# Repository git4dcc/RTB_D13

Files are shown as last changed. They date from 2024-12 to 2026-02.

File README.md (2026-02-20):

# RTB_D13




My Homebrew [D13](https://rtb4dcc.de/hardware/decoder/d13/) LED decoder is a drop in design for Minitrix (#15791) coach with no mechanical modification required. The decoder is designed to integrate into the [RTB](https://rtb4dcc.de/concept/) digital control infrastructure.

<details>
<summary>See also</summary>

- [RTB_D12 - custom](/../../../../git4dcc/RTB_D12) (Fleischmann V100)
- [RTB_D15 - custom](/../../../../git4dcc/RTB_D15) (Minitrix V160)
- [RTB_D16 - NEM651](/../../../../git4dcc/RTB_D16)
- [RTB_D20 - NEM651](/../../../../git4dcc/RTB_D20)
- [RTB_D21 - Next18](/../../../../git4dcc/RTB_D21)
- [RTB_D22 - Plux16](/../../../../git4dcc/RTB_D22)
- [RTB_D23 - NEM652](/../../../../git4dcc/RTB_D23)

</details>

<details>
<summary>User Guides</summary>

- User Guide - DE
- [User Guide - EN](https://rtb4dcc.de/rtb_decoder_reference_en/)

</details>

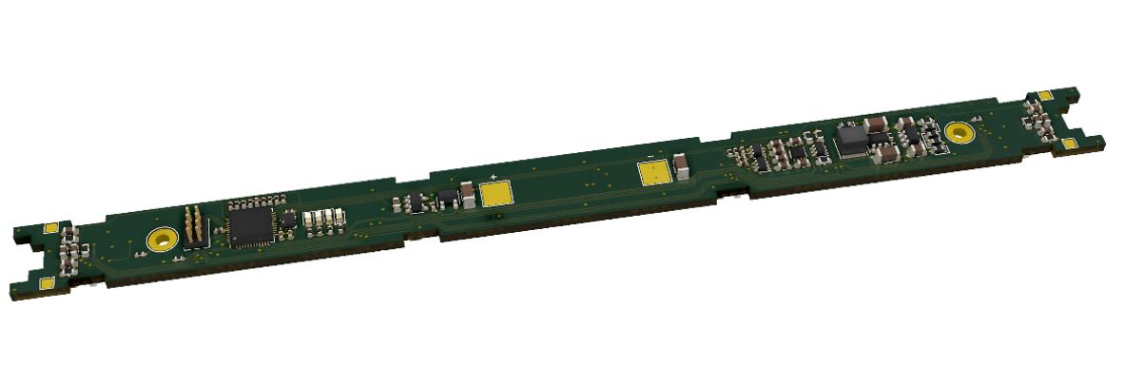
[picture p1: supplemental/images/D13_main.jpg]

<br>

## Decoder features
- **DCC**
  - DCC-A automatic logon
  - DCC-R protocol extension
  - Service Mode Programming
- **Railcom**
  - Channel 1/2
  - POM, xPOM
  - DYN: QoS, Track-Voltage, Scap-Voltage, Temp, Ambient light
- 1x4F/2.8V SCAP (on PCB)
- Inrush limited
- step up/down converter
- max track voltage 25V
- Corridor (11 LEDs), Cabin (13 LEDs), Lavatory (2 LEDs)
- Status LEDs: heartbeat, charging, no-power
- motion sensor
- ambient light sensor
- fast firmware update within seconds on main tracks via DCC-R

# Hardware
The current PCB layout uses SMD footprints with 0.5mm pitch and mainly 0603 parts. Reflow soldering is recommended whereas handsoldering will be difficult.

## PCB
- 4-layer PCB, FR4, 1mm
- CPU: AVR64DA48

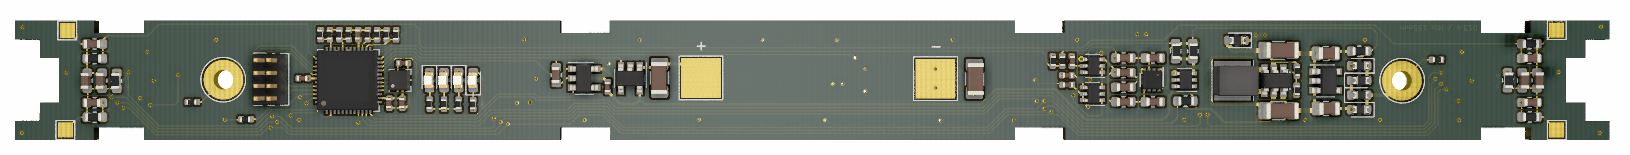
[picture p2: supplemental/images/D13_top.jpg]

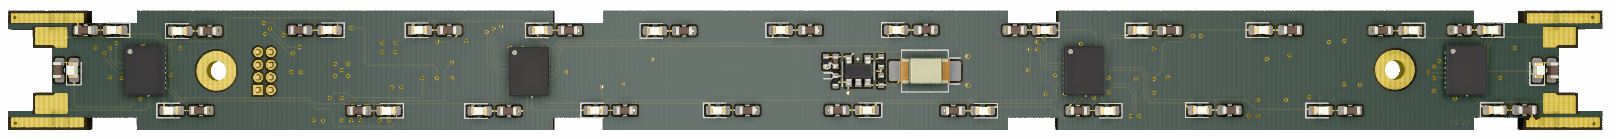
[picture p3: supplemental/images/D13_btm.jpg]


## Kicad
[Schematic](doc/D13_schematic.pdf) | [Layout](doc/D13_layout.pdf) | [Gerber](gerber)

<details>
<summary>Dependency</summary>
<br>

:yellow_circle: Requires my Kicad project library [RTB_SamacSys](https://github.com/git4dcc/RTB_SamacSys) in the same directory tree.

</details>

## Firmware
Filename structure: { **pcb** }{ **code** }{ **version** }.hex

Example: **D13F0001**.hex

| | Description |
| --- | --- |
| **pcb** | Name of matching hardware (**D13**) |
| **code** | Type of code contained (**R**=rom, **B**=bootloader, **F**=flash, **U**=bld update, **P**=UPDI factory code) |
| **version** | Release version (**####**) |

[Firmware files](firmware)

# Images
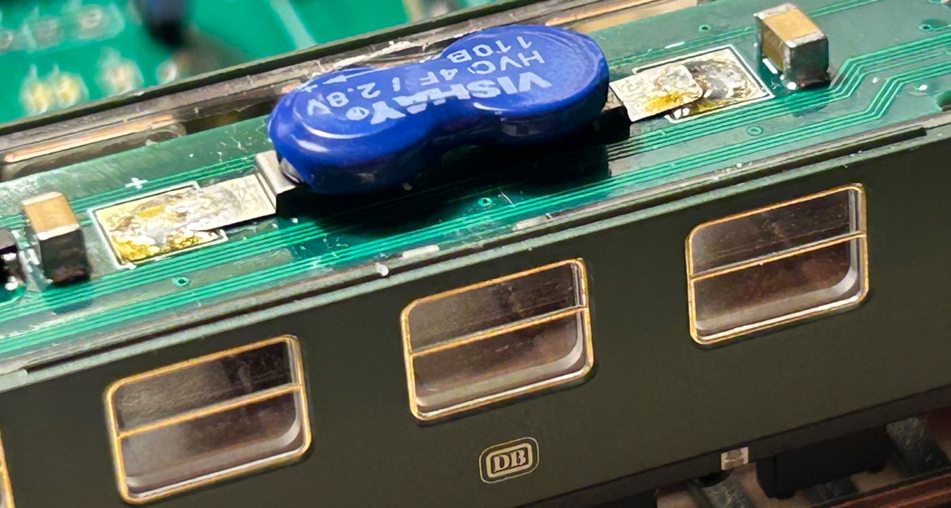
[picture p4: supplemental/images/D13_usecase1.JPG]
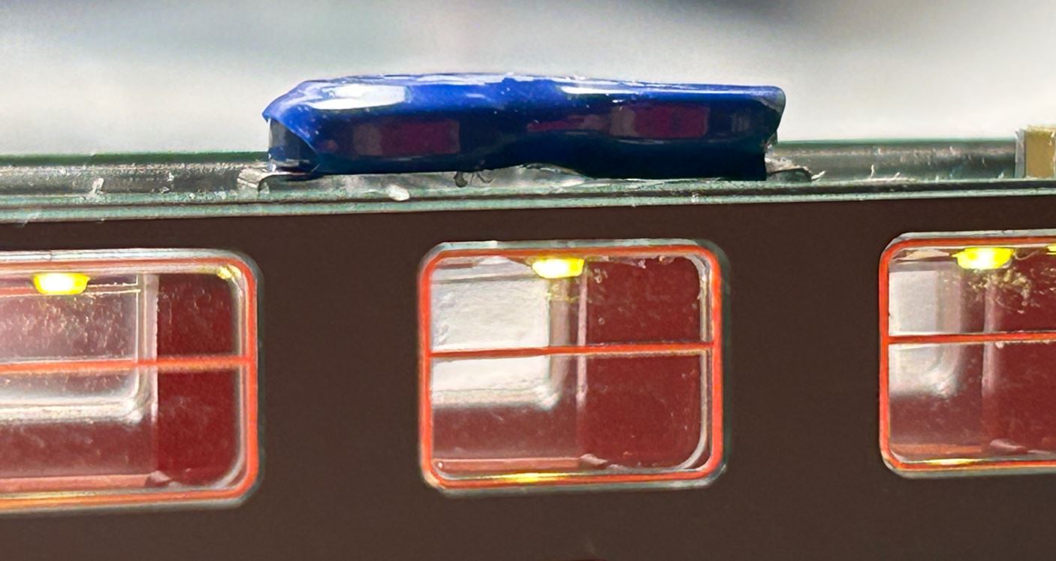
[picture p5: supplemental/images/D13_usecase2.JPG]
 

# YouTube
See the D13 decoder in action.<br><br>
[](https://youtube.com/watch?v=nAJpYsdv1IA)
[](https://youtube.com/watch?v=Nc4pEvq2rl0)
[](https://youtube.com/watch?v=AlGYfNOvHXI)

This project is intended for hobby use only and is distributed in accordance with the Apache License 2.0 agreement.

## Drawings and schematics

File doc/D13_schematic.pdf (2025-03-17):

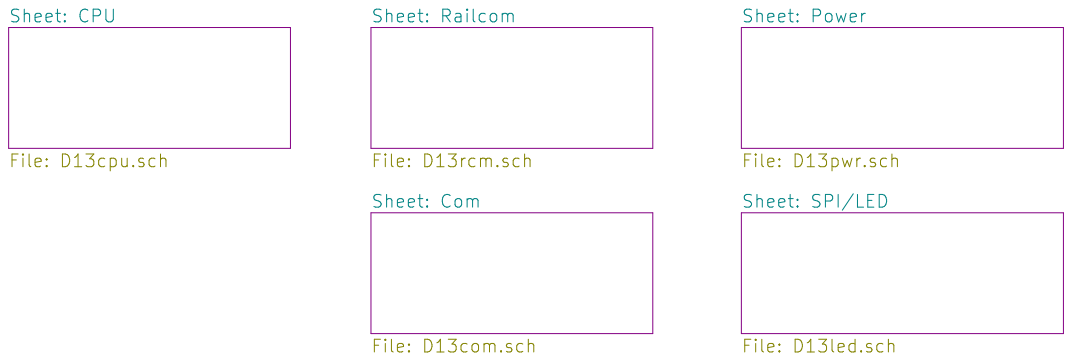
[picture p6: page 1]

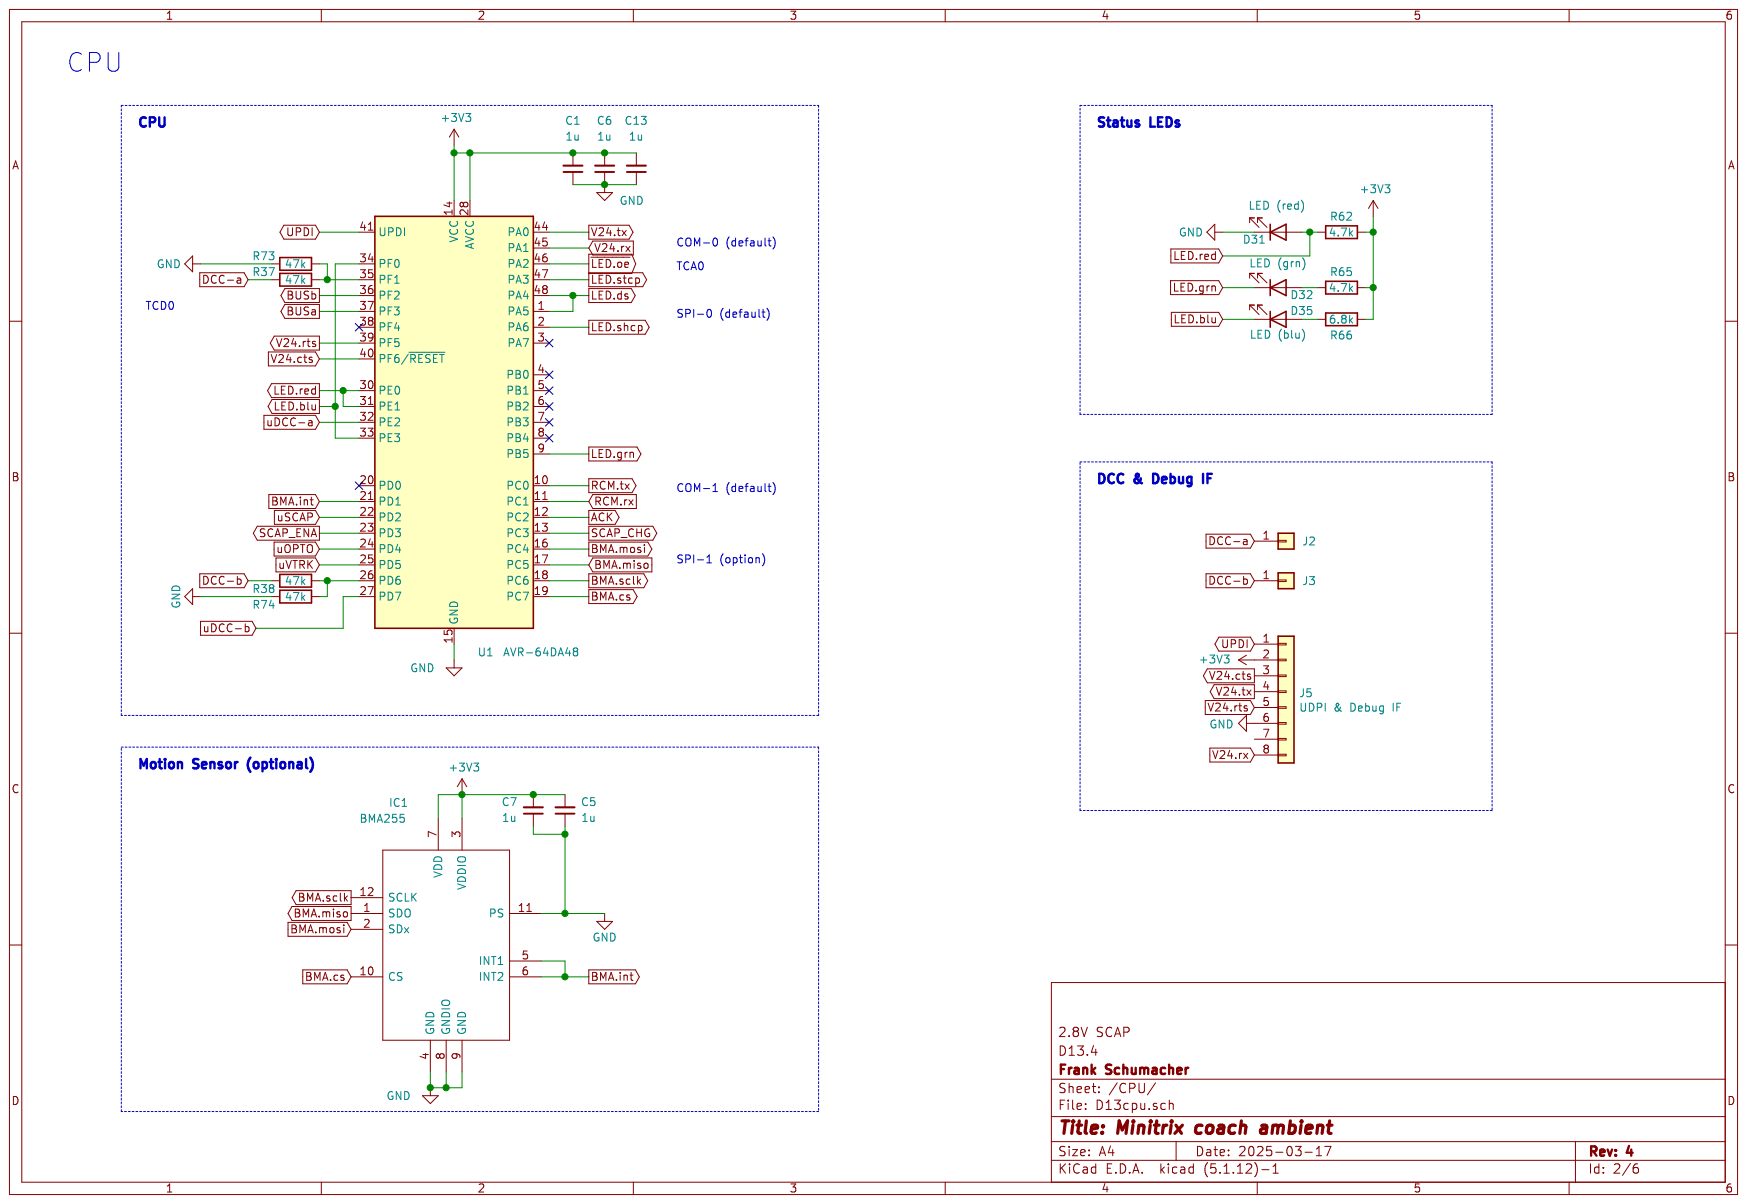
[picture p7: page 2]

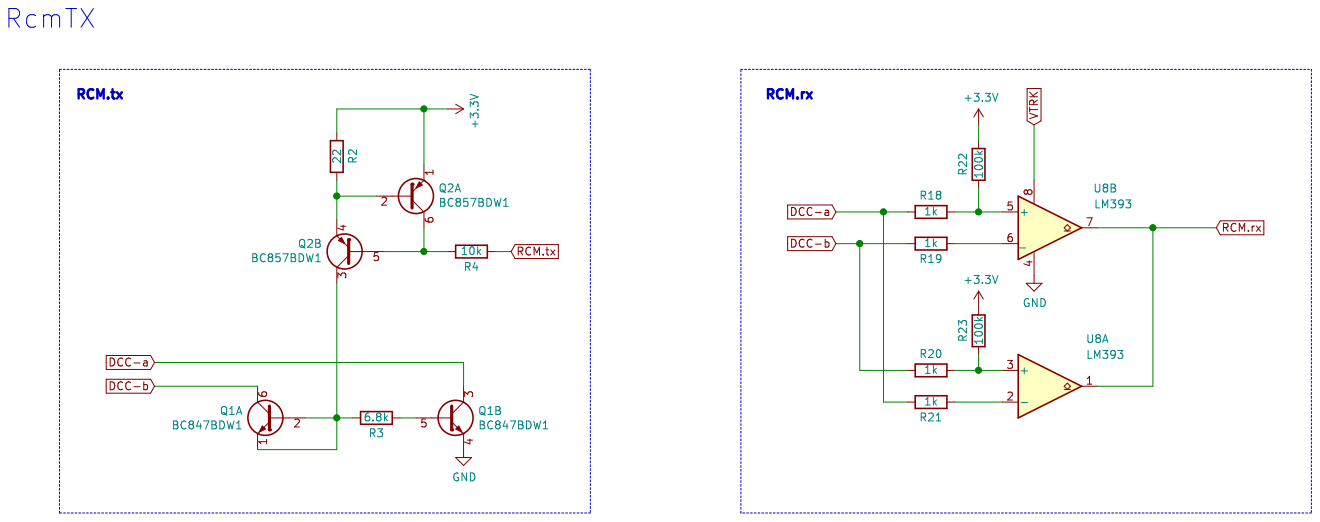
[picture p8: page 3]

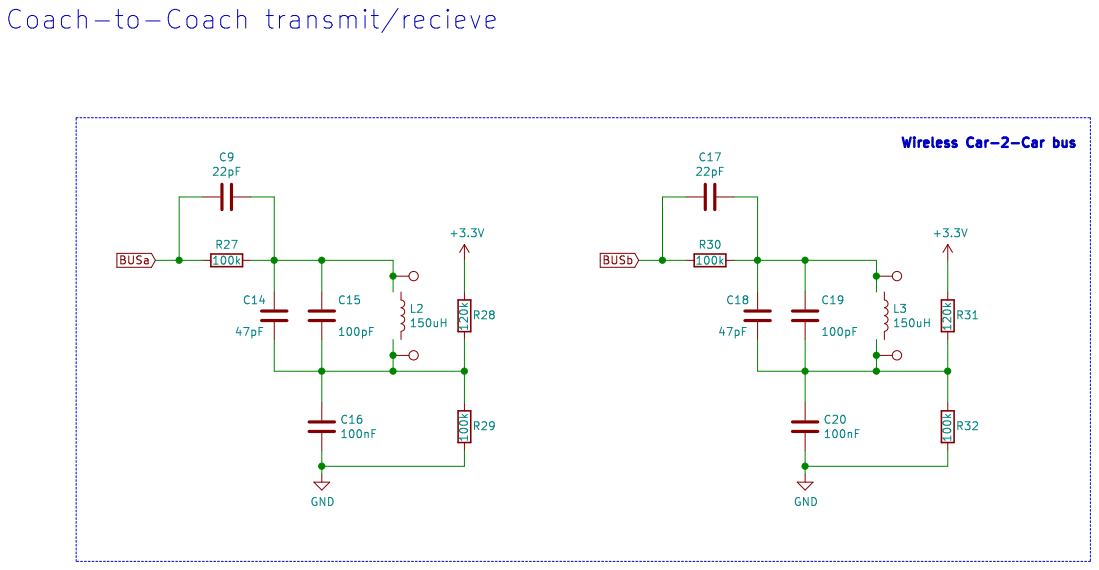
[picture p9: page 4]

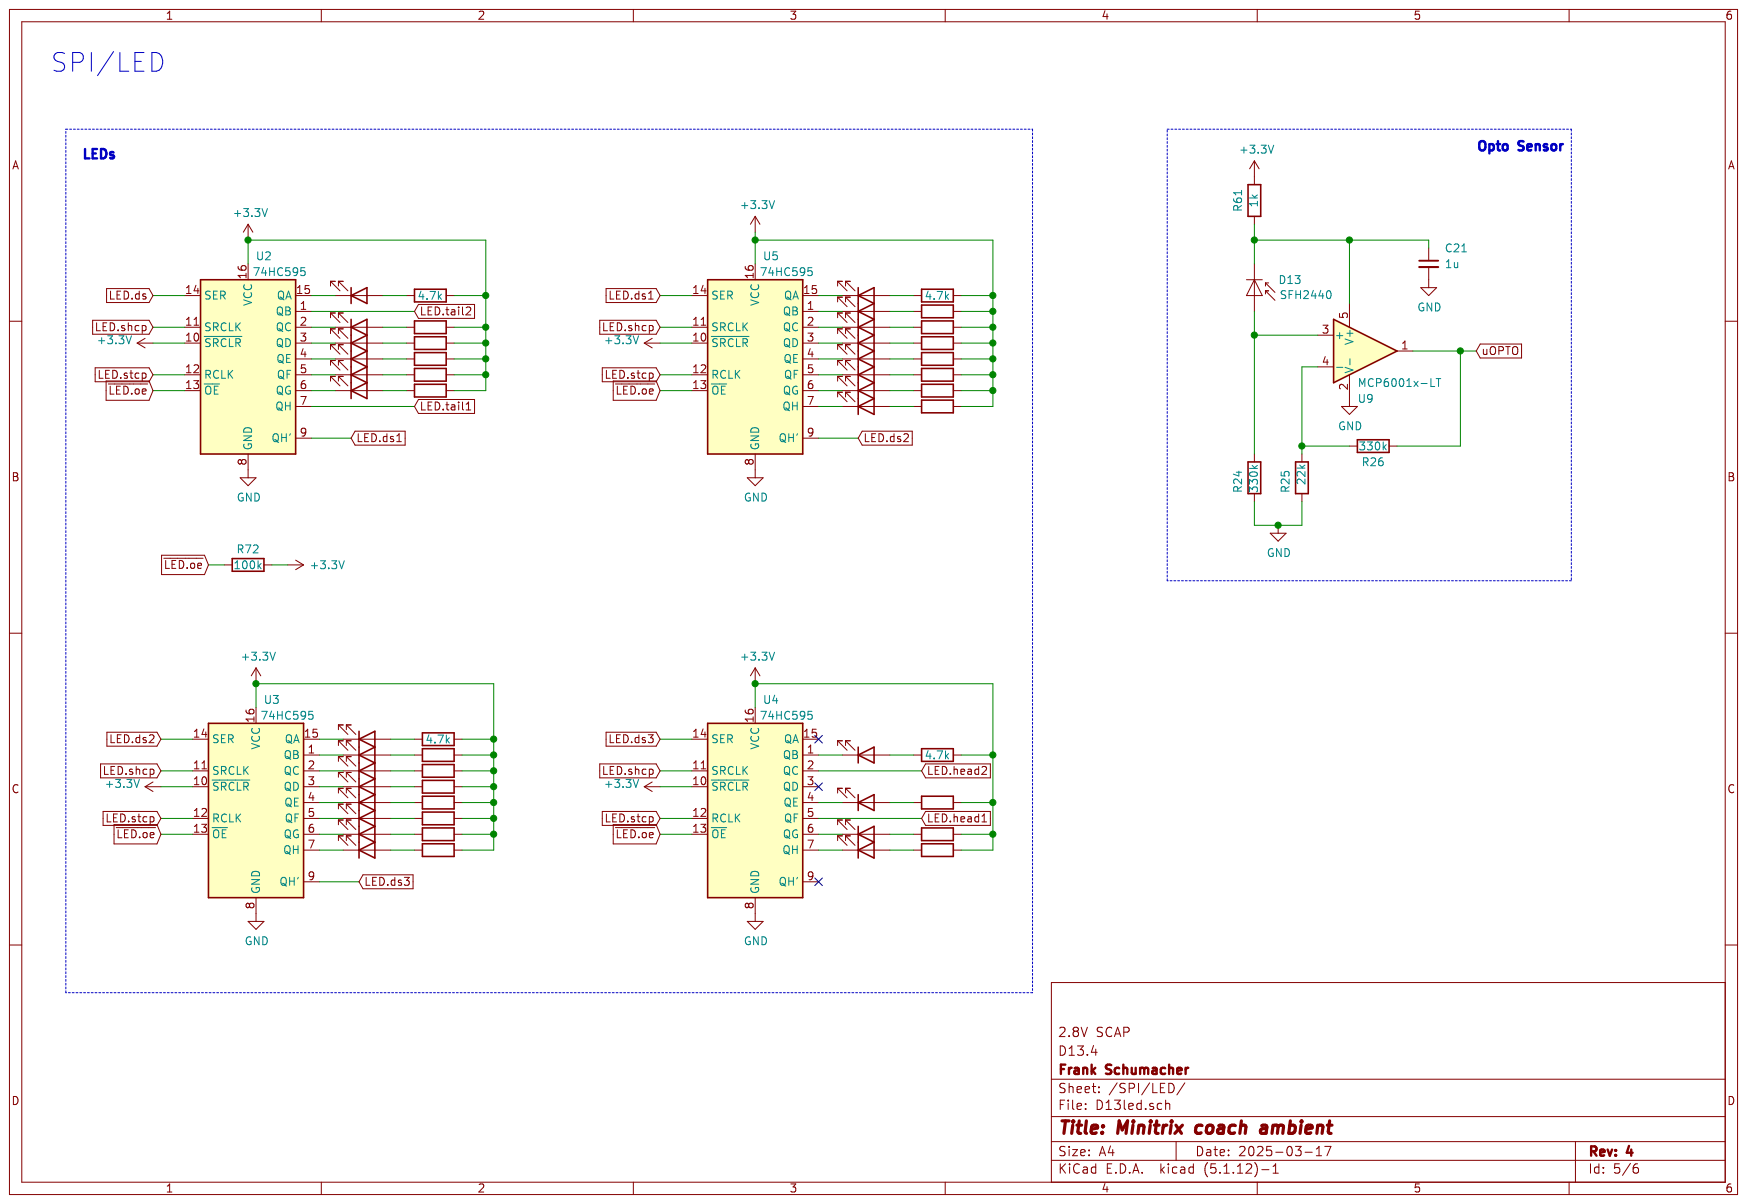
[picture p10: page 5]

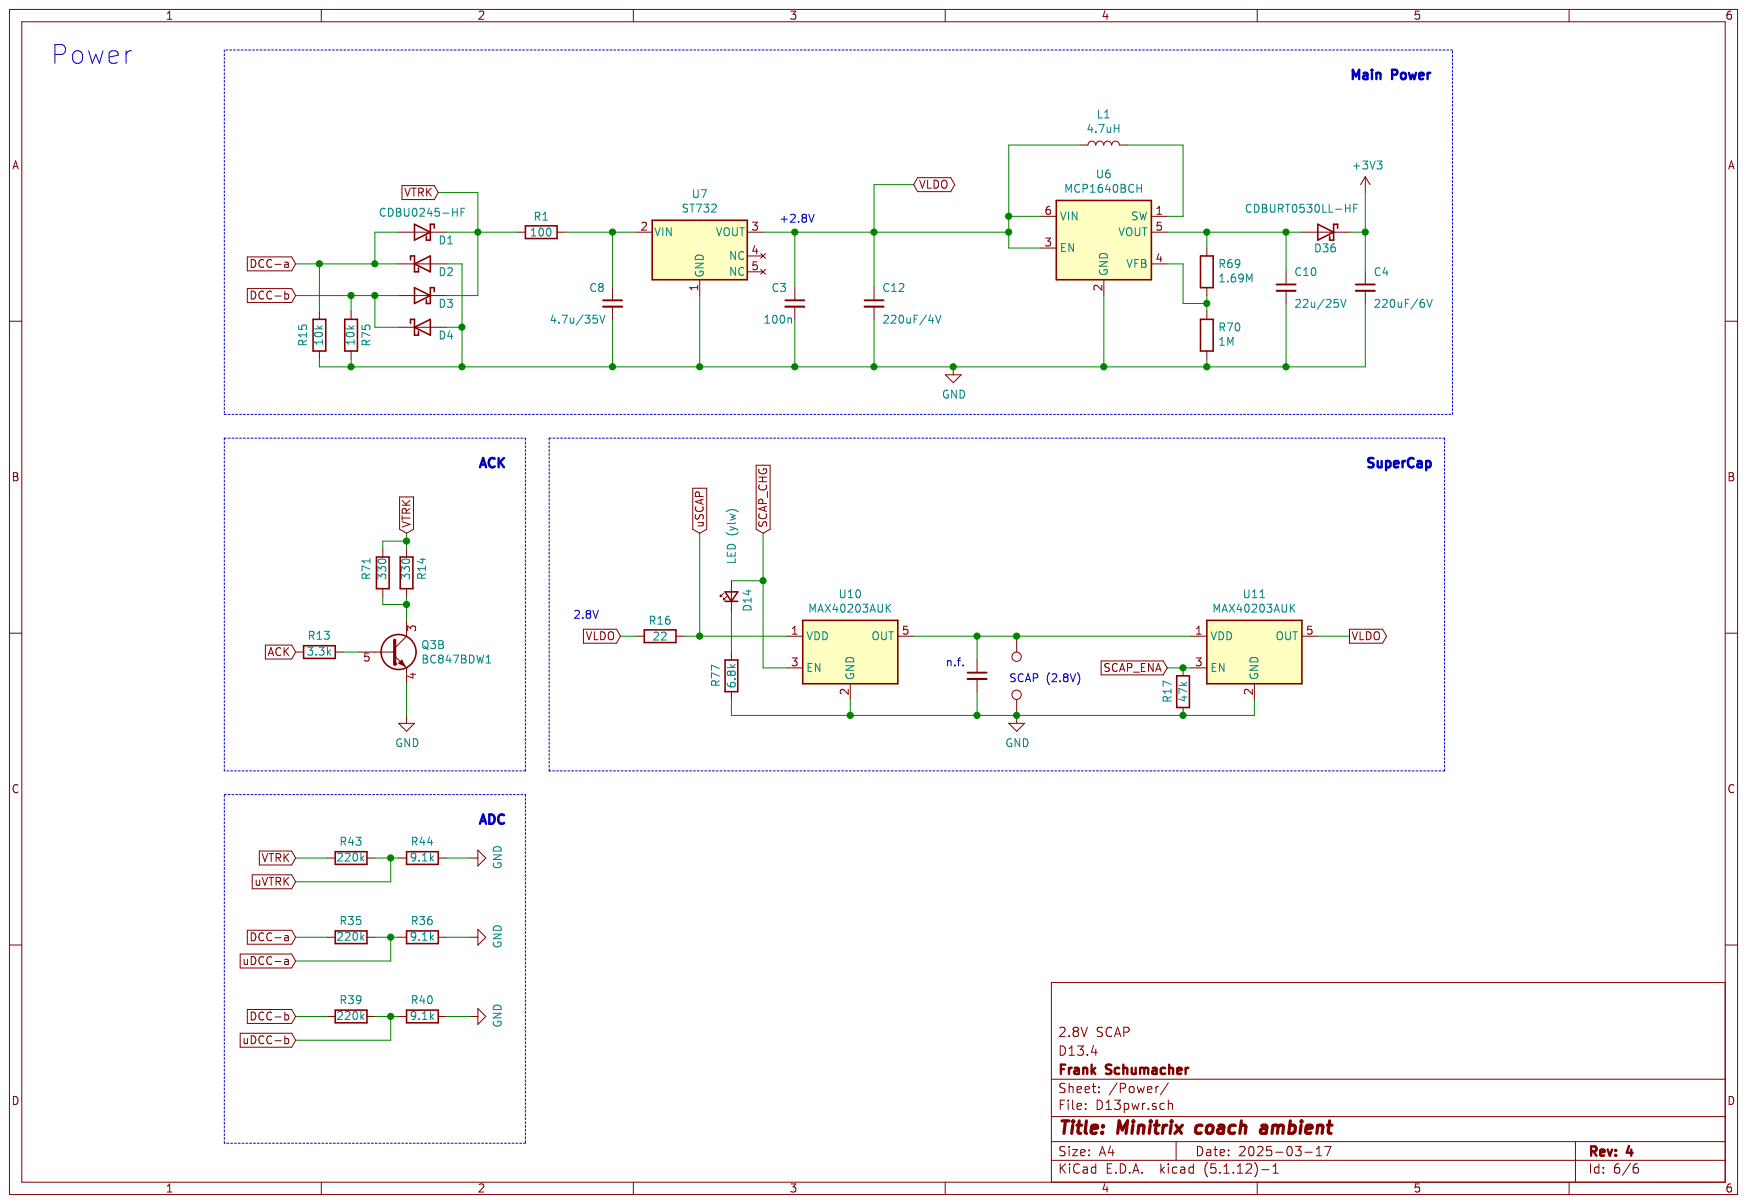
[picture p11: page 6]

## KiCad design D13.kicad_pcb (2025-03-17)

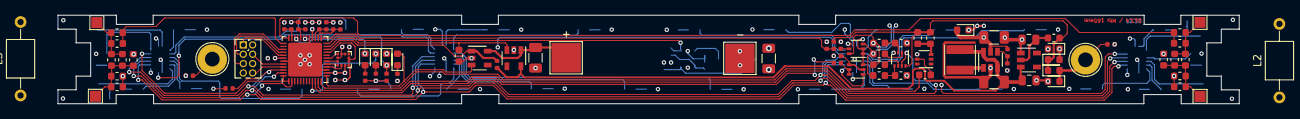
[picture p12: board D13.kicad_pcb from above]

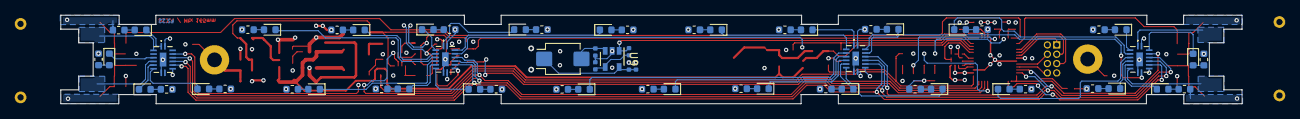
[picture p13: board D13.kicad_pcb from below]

Board: 4 copper layers, 160.8 x 12.0 mm, 153 parts (63 on the bottom side), 117 nets.

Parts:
C1, C5, C6, C7, C13, C21: 1u; C_0402_1005Metric
C2: <=100uF/4V; C_1206_3216Metric
C3: 4.7u; C_0805_2012Metric
C4: 220uF/6V; C_1206_3216Metric
C8: 4.7u/35V; C_0805_2012Metric
C9, C17: 22pF; C_0603_1608Metric
C10: 22u/25V; C_1206_3216Metric
C12: 220uF/4V; C_1206_3216Metric
C14, C18: 47pF; C_0603_1608Metric
C15, C19: 100pF; C_0603_1608Metric
C16, C20: 100nF; C_0603_1608Metric
D1: CDBU0245-HF; D_0603_1608Metric
D2, D3, D4: D_Schottky; D_0603_1608Metric
D5, D6, D7, D8, D9, D10, D11, D12, D14, D15, D16, D17, D18, D19, D20, D21, D22, D23, D24, D25, D26, D27, D28, D29, D30, D31, D32, D33, D34, D35: LED; LED_0603_1608Metric
D13: SFH2440; Osram_SMD-DIL2_4.5x4.0mm
D36: CDBURT0530LL-HF; D_0603_1608Metric
IC1: BMA255; LGA-12_2x2mm_P0.5mm
J2, J3: Conn_01x01; TestPoint_THTPad_D4.0mm_Drill2.0mm
J5: UDPI; PinHeader_2x04_P1.27mm_Vertical
L1: 4.7uH; L_Taiyo-Yuden_MD-4040
L2, L3: 150uH; L_Axial_L5.0mm_D3.6mm_P10.00mm_Horizontal_Murata_BL01RN1A2A2
Q1, Q3: BC847BDW1; SOT-363_SC-70-6
Q2: BC857BDW1; SOT-363_SC-70-6
R1: 100; R_0603_1608Metric
R2, R16: 22; C_0402_1005Metric
R3, R77: 6.8k; C_0402_1005Metric
R4: 10k; C_0402_1005Metric
R5, R6, R7, R8, R9, R10, R11, R12, R45, R46, R47, R48, R49, R50, R51, R52, R53, R54, R55, R56, R57, R58, R59, R60, R63, R64: 4.7k; C_0603_1608Metric
R13: 3.3k; R_0603_1608Metric
R14, R71: 470; R_0603_1608Metric
R15, R75: 10k; R_0402_1005Metric
R17: 47k; C_0603_1608Metric
R18, R19, R20, R21: 1k; C_0603_1608Metric
R22, R23: 100k; C_0603_1608Metric
R24, R26: 330k; R_0402_1005Metric
R25: 22k; R_0402_1005Metric
R27, R29, R30, R32: 100k; R_0603_1608Metric
R28, R31: 120k; R_0603_1608Metric
R35, R39, R43: 220k; R_0402_1005Metric
R36, R40, R44: 9.1k; R_0402_1005Metric
R37, R73: 47k; R_0402_1005Metric
R38, R62, R65, R66, R74: R; R_0402_1005Metric
R61: 1k; R_0402_1005Metric
R69: 1.69M; R_0402_1005Metric
R70: 1M; R_0402_1005Metric
R72: 100k; R_0402_1005Metric
TP1, TP2, TP3, TP4: TestPoint; TestPoint_Pad_1.5x1.5mm
TP5, TP6: TestPoint; TestPoint_Pad_4.0x4.0mm
U1: AVR-64DA48; UQFN-48-1EP_6x6mm_P0.4mm_EP4.62x4.62mm
U2, U3, U4, U5: 74HC595; 74HC595BQ115
U6: MCP1640BCH; SOT-23-6
U7: ST732; SOT-23-5
U8: LM393; DFN-8-1EP_NG_2x2mm_Pitch0.5mm
U9: MCP6001x-LT; SOT-23-5
U10, U11: MAX40203AUK; SOT-23-5

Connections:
+3V3: C1.2, C4.1, C5.2, C6.2, C7.2, C13.2, D36.1, IC1.3, IC1.7, J5.2, Q2.1, R2.1, R5.1, R6.1, R7.1, R8.1, R9.1, R10.1, R11.1, R12.1, R22.1, R23.1, R28.2, R31.2, R45.1, R46.1, R47.1, R48.1, R49.1, R50.1, R51.1, R52.1, R53.1, R54.1, R55.1, R56.1, R57.1, R58.1, R59.1, R60.1, R61.2, R62.1, R63.1, R64.1, R65.1, R66.1, R72.1, U1.14, U1.28, U1.42, U2.10, U2.16, U3.10, U3.16, U4.10, U4.16, U5.10, U5.16
ACK: R13.1, U1.12
BMA.cs: IC1.10, U1.19
BMA.int: IC1.5, IC1.6, U1.21
BMA.miso: IC1.1, U1.17
BMA.mosi: IC1.2, U1.16
BMA.sclk: IC1.12, U1.18
BUSa: C9.2, R27.2, U1.37
BUSb: C17.2, R30.2, U1.36
DCC-a: D1.2, D2.1, J2.1, Q1.3, R15.2, R18.1, R21.1, R35.1, R37.2
DCC-b: D3.2, D4.1, J3.1, Q1.6, R19.1, R20.1, R38.2, R39.1, R75.2
GND: C1.1, C2.2, C3.2, C4.2, C5.1, C6.1, C7.1, C8.2, C10.2, C12.2, C13.1, C16.2, C20.2, C21.2, D2.2, D4.2, D31.1, IC1.4, IC1.8, IC1.9, IC1.11, J5.6, Q1.4, Q3.4, R15.1, R17.2, R24.1, R25.1, R29.1, R32.1, R36.2, R40.2, R44.2, R70.1, R73.2, R74.2, R75.1, R77.2, TP6.1, U1.15, U1.29, U1.43, U1.49, U2.8, U3.8, U4.8, U5.8, U6.2, U7.1, U8.4, U9.2, U10.2, U11.2
LED.blu: D35.1, U1.33, U1.34
LED.ds: U1.1, U1.48, U2.14
LED.ds1: U2.9, U5.14
LED.ds2: U3.14, U5.9
LED.ds3: U3.9, U4.14
LED.grn: D32.1, U1.9
LED.red: D31.2, R62.2, U1.30, U1.31
LED.shcp: U1.2, U2.11, U3.11, U4.11, U5.11
LED.stcp: U1.47, U2.12, U3.12, U4.12, U5.12
unnamed: C2.1, TP5.1, U10.5, U11.1
unnamed: C8.1, R1.1, U7.2
unnamed: C10.1, D36.2, R69.2, U6.5
unnamed: C9.1, C14.1, C15.1, R27.1, TP1.1
unnamed: C14.2, C15.2, C16.1, R28.1, R29.2, TP2.1
unnamed: C17.1, C18.1, C19.1, R30.1, TP3.1
unnamed: C18.2, C19.2, C20.1, R31.1, R32.2, TP4.1
unnamed: C21.1, D13.1, R61.1, U9.5
unnamed: D5.1, U3.15
unnamed: D5.2, R5.2
unnamed: D6.1, U3.1
unnamed: D6.2, R6.2
unnamed: D7.1, U2.2
unnamed: D7.2, R7.2
unnamed: D8.1, U2.3
unnamed: D8.2, R8.2
unnamed: D9.1, U2.4
unnamed: D9.2, R9.2
unnamed: D10.1, U2.5
unnamed: D10.2, R10.2
unnamed: D11.1, U2.6
unnamed: D11.2, R11.2
unnamed: D12.1, U2.15
unnamed: D12.2, R12.2
unnamed: D13.2, R24.2, U9.3
unnamed: D14.1, R77.1
unnamed: D15.1, U5.15
unnamed: D15.2, R45.2
unnamed: D16.1, U5.1
unnamed: D16.2, R46.2
unnamed: D17.1, U5.3
unnamed: D17.2, R47.2
unnamed: D18.1, U5.2
unnamed: D18.2, R48.2
unnamed: D19.1, U5.4
unnamed: D19.2, R49.2
unnamed: D20.1, U5.5
unnamed: D20.2, R50.2
unnamed: D21.1, U5.6
unnamed: D21.2, R51.2
unnamed: D22.1, U5.7
unnamed: D22.2, R52.2
unnamed: D23.1, U3.2
unnamed: D23.2, R53.2
unnamed: D24.1, U3.3
unnamed: D24.2, R54.2
unnamed: D25.1, U3.4
unnamed: D25.2, R55.2
unnamed: D26.1, U3.5
unnamed: D26.2, R56.2
unnamed: D27.1, U3.6
unnamed: D27.2, R57.2
unnamed: D28.1, U3.7
unnamed: D28.2, R58.2
unnamed: D29.1, U4.1
unnamed: D29.2, R59.2
unnamed: D30.1, U4.4
unnamed: D30.2, R60.2
unnamed: D32.2, R65.2
unnamed: D33.1, U4.6
unnamed: D33.2, R63.2
unnamed: D34.1, U4.7
unnamed: D34.2, R64.2
unnamed: D35.2, R66.2
unnamed: L1.2, U6.1
unnamed: Q1.1, Q1.2, Q2.3, R3.1
unnamed: Q1.5, R3.2
unnamed: Q2.2, Q2.4, R2.2
unnamed: Q2.5, Q2.6, R4.1
unnamed: Q3.3, R14.1, R71.1
unnamed: Q3.5, R13.2
unnamed: R18.2, R22.2, U8.5
unnamed: R19.2, U8.6
unnamed: R20.2, R23.2, U8.3
unnamed: R21.2, U8.2
unnamed: R25.2, R26.2, U9.4
unnamed: R37.1, R73.1, U1.35
unnamed: R38.1, R74.1, U1.26
unnamed: R69.1, R70.2, U6.4
RCM.rx: U1.11, U8.1, U8.7
RCM.tx: R4.2, U1.10
SCAP_CHG: D14.2, U1.13, U10.3
SCAP_ENA: R17.1, U1.23, U11.3
UPDI: J5.1, U1.41
V24.cts: J5.3, U1.40
V24.rts: J5.5, U1.39
V24.rx: J5.8, U1.45
V24.tx: J5.4, U1.44
VLDO: C3.1, C12.1, L1.1, R16.2, U6.3, U6.6, U7.3, U11.5
VTRK: D1.1, D3.1, R1.2, R14.2, R43.1, R71.2, U8.8
uDCC-a: R35.2, R36.1, U1.32
uDCC-b: R39.2, R40.1, U1.27
uOPTO: R26.1, U1.24, U9.1
uSCAP: R16.1, U1.22, U10.1
uVTRK: R43.2, R44.1, U1.25
~LED.oe: R72.2, U1.46, U2.13, U3.13, U4.13, U5.13

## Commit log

2025-03-17 mod: LED animation
    [D13.kicad_pcb, D13.sch, D13com.sch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]
2025-08-05 mod: led automation
